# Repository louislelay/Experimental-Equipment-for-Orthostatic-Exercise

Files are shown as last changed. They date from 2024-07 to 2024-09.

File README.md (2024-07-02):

# Experimental Equipment for Orthostatic Exercise

This is the repository for the Experimental Equipment for Orthostatic Exercise project, developed by the Real World Robot Informatics Lab at the University of Tokyo. The goal is to create a robotic assistive system designed to aid individuals in standing up from a soft chair.

This project is part of the research conducted by Prof. Qi An. 

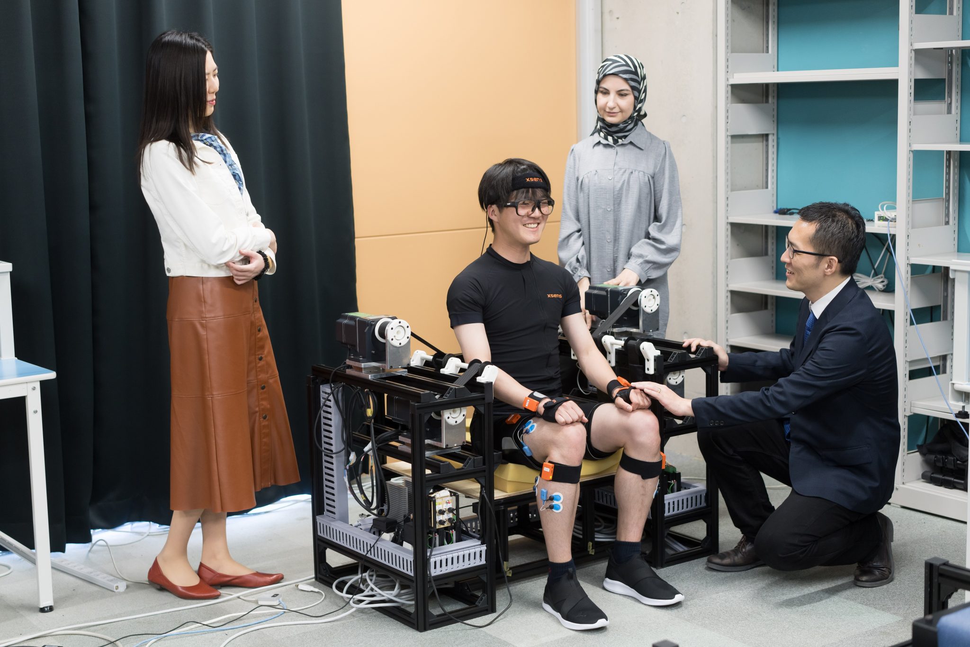
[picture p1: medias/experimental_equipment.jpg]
Experimental Equipment


[Real World Robot Informatics Lab's Website](https://www.robot.t.u-tokyo.ac.jp/yamalab/index.html)

[Qi An's Website](https://www.robot.t.u-tokyo.ac.jp/anlab/)

## Code

### Prerequisites

The project is implemented in MATLAB. Ensure you have MATLAB installed along with the "Data Acquisition Toolbox."

Additionally, two National Instruments libraries are required to interface with the National Instruments USB-6009 device. The executables, named "ni-daqmx_24.3_online.exe" and "ni-system-configuration_24.3_online.exe," are located at the root of the project.

All code files are located in the "src" folder.

### Calibration

Due to the initial force applied to the sensors, you must run the "calibration.m" program. Ensure the switch is set to remote mode.

This program will reverse the motors to loosen the strap and collect 1000 filtered values from all four sensors. It calculates the mean of these values, providing an offset applied in subsequent programs via a JSON file.

### Using the Chair (still in development)

To operate the chair, run the "main.m" program. This program instructs the motors to apply a 40N force to the strap using a PID loop. It monitors real-time values to detect when the user intends to stand. By increasing the force to 100N, the strap tightens, making it easier for the user to stand by converting the chair from soft to firm.

### Debugging

To read values in real-time and control the chair manually, run the "debug.m" program. By default, it won't display any values. You need to pass arguments to view specific data.

- `debug` - No display.
- `debug('-raw')` - Displays raw sensor values.
- `debug('-filt')` - Displays filtered sensor values.
- `debug('-calib')` - Displays calibrated, filtered values.
- `debug('-f')` - Displays resultant forces from each motor.

You can combine arguments to view multiple data sets simultaneously, such as `debug('-filt', '-calib')` to display both filtered and calibrated values.

These arguments are also applicable to the "main.m" program.

### Storing Data

To analyze the values and create a program that detects variations, we need to store data on the force evolution when someone is standing up from the chair. This is why we developed the program "get_values.m," which collects sensor information and stores it in "data_stored.mat." Each time, it will prompt for a name to be associated with the new data.

## CAD

The "cad" folder contains the SolidWorks CAD files for the project.

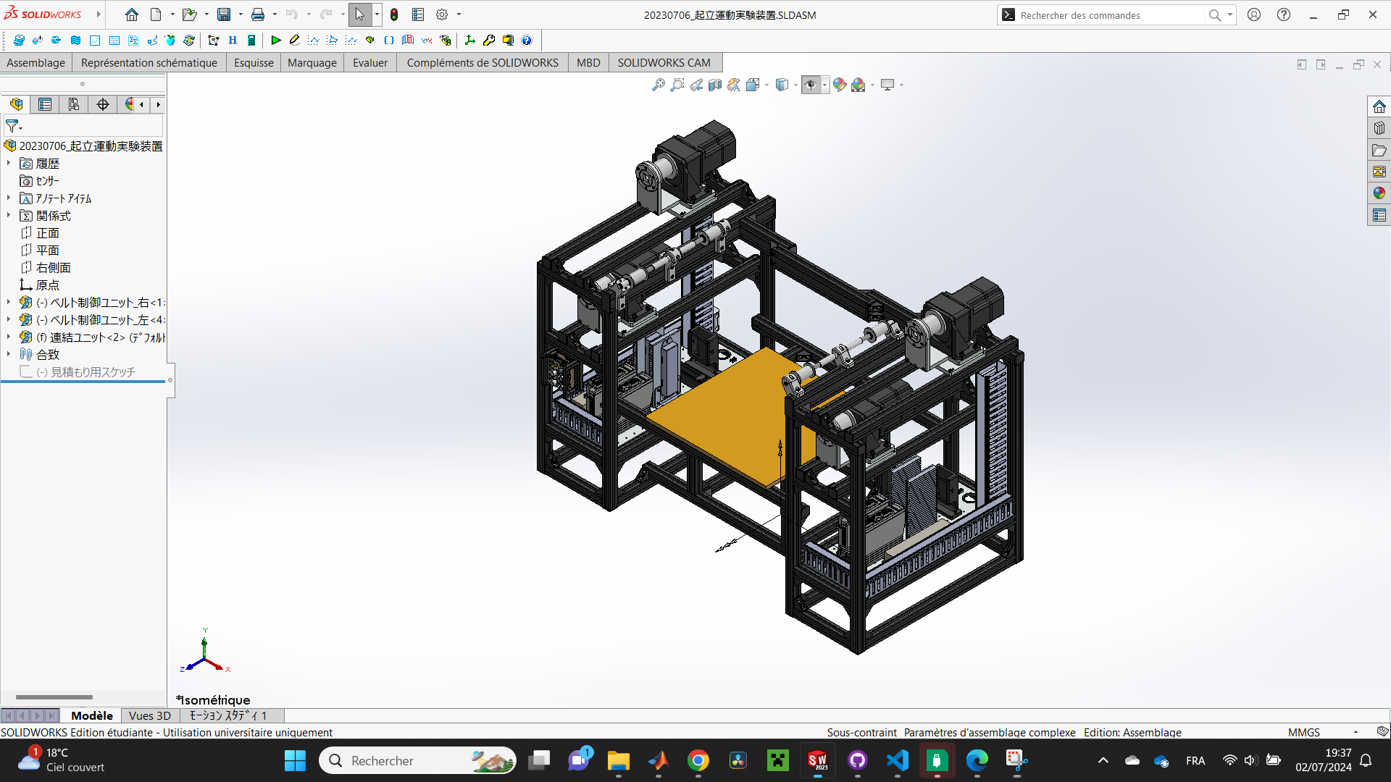
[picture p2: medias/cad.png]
CAD screenshot


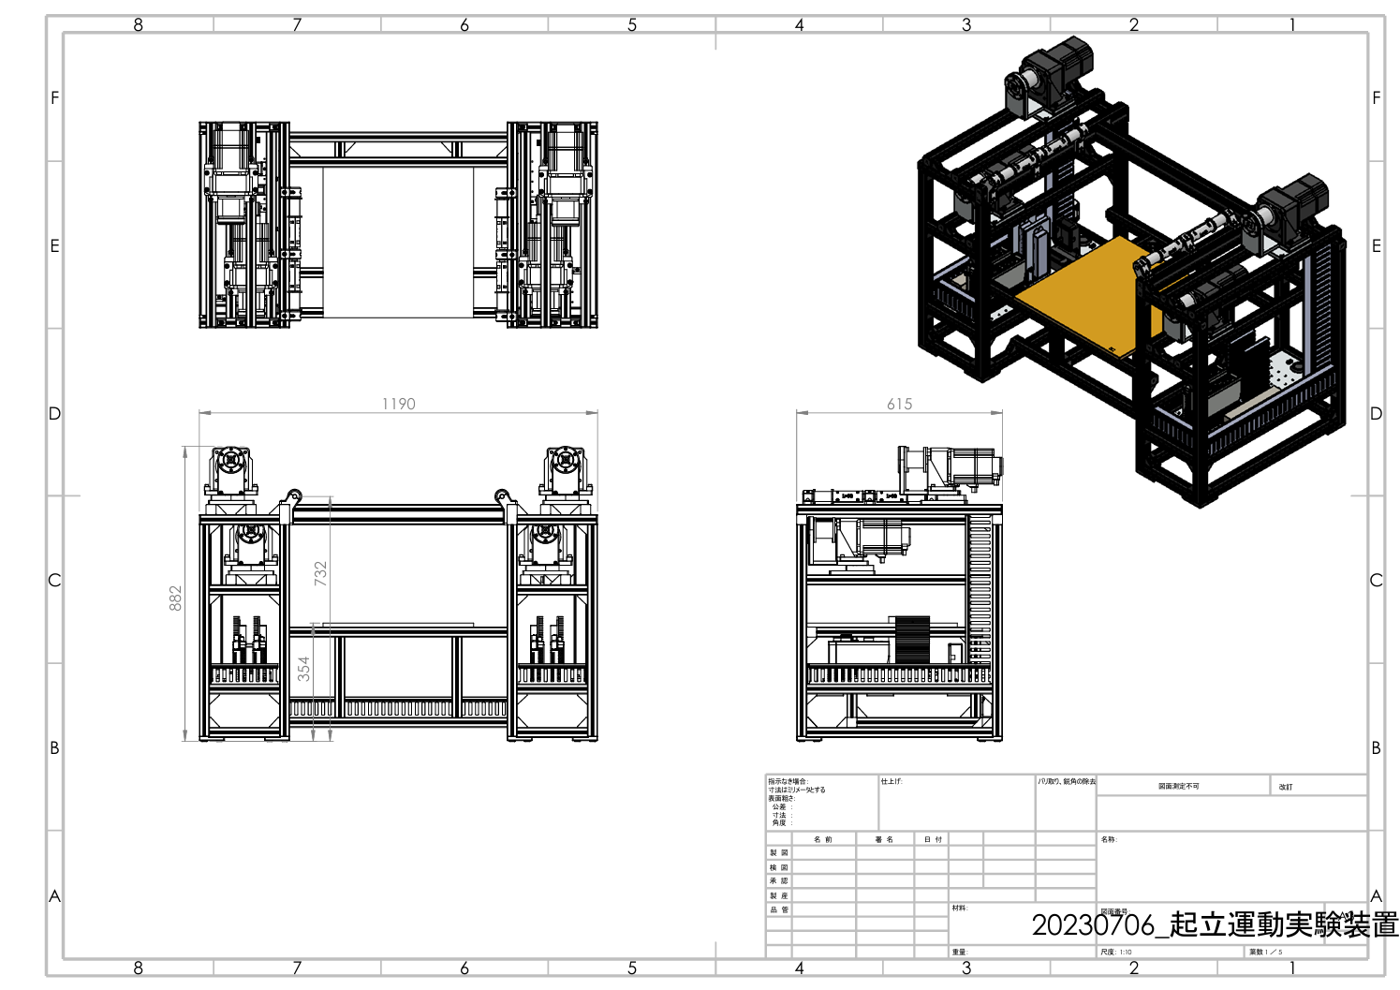
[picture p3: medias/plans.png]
Plans screenshot


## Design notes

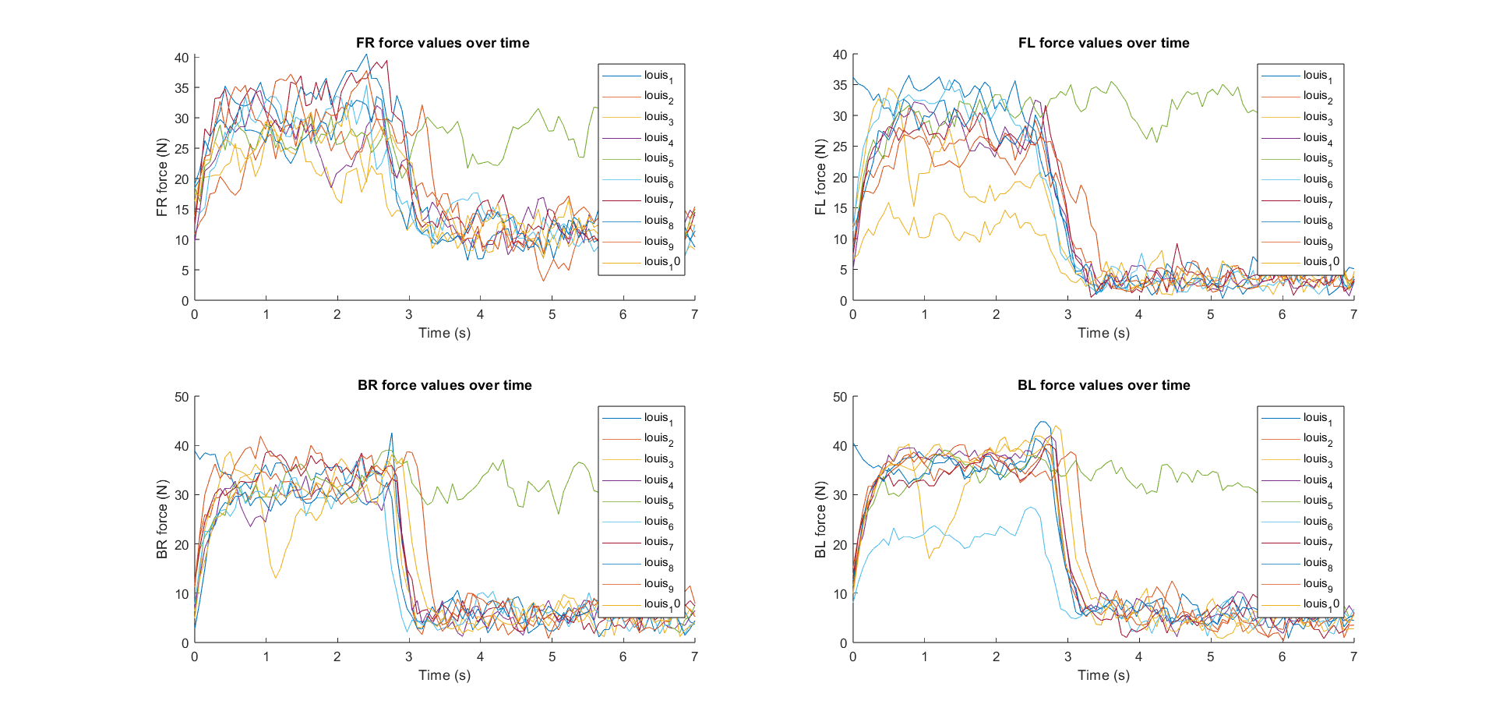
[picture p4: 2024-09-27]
src/treshold.png

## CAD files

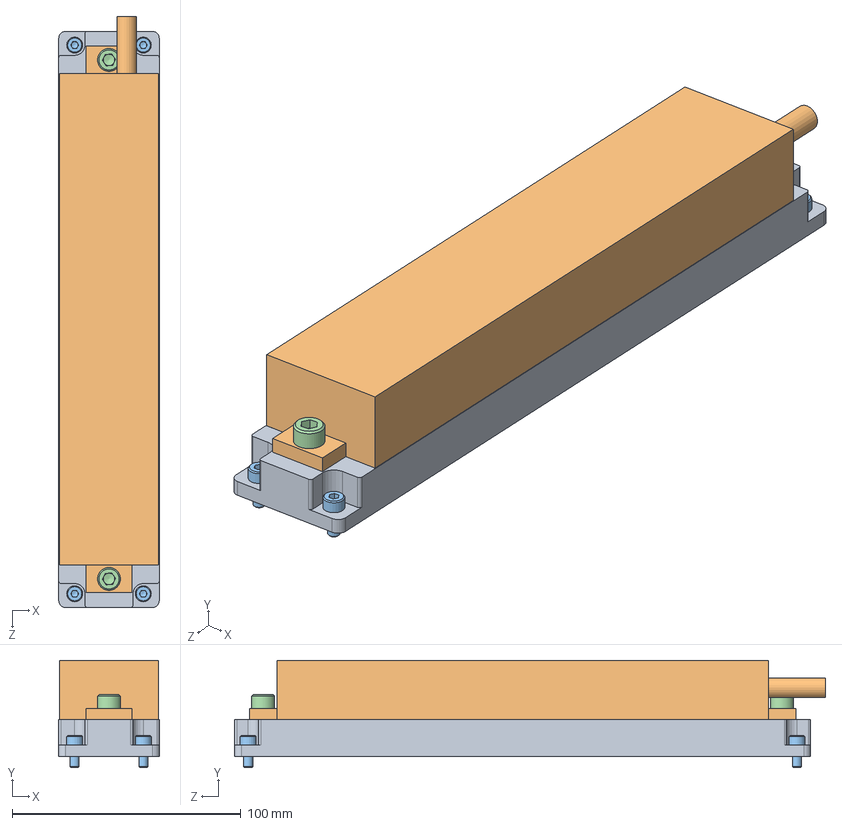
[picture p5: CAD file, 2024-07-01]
cad/コンセント.SLDASM
44.0 x 47.0 x 258.5 mm
TAP-K4-10用ベース
TAP-K4-10
CB4-10 x 4
CB6-12 x 2

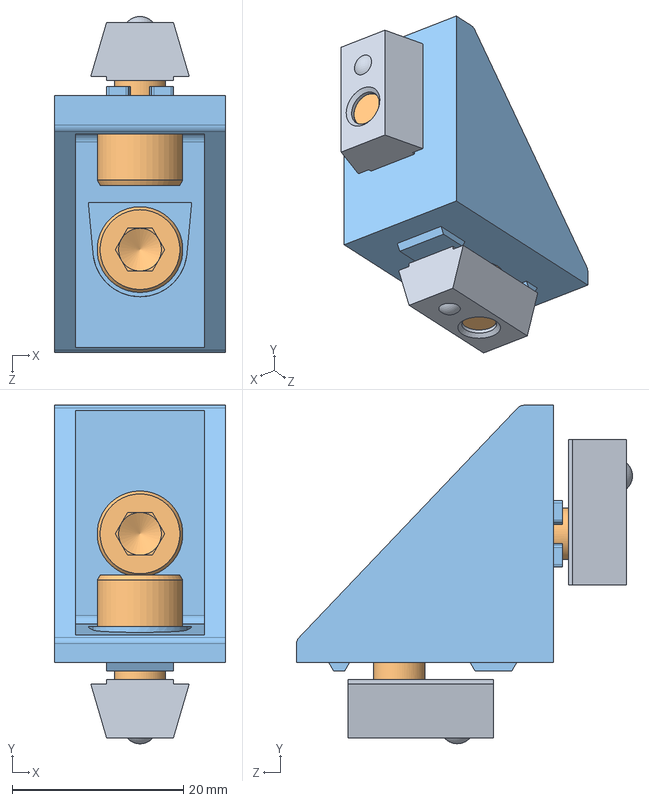
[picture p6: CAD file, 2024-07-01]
cad/HBLFSNB6-SEP.sldasm
20.0 x 39.5 x 39.2 mm
HNTP6-6_app x 2
HBLFSN6_CBM6-12 x 2
HBLFSNB6-SEP_b

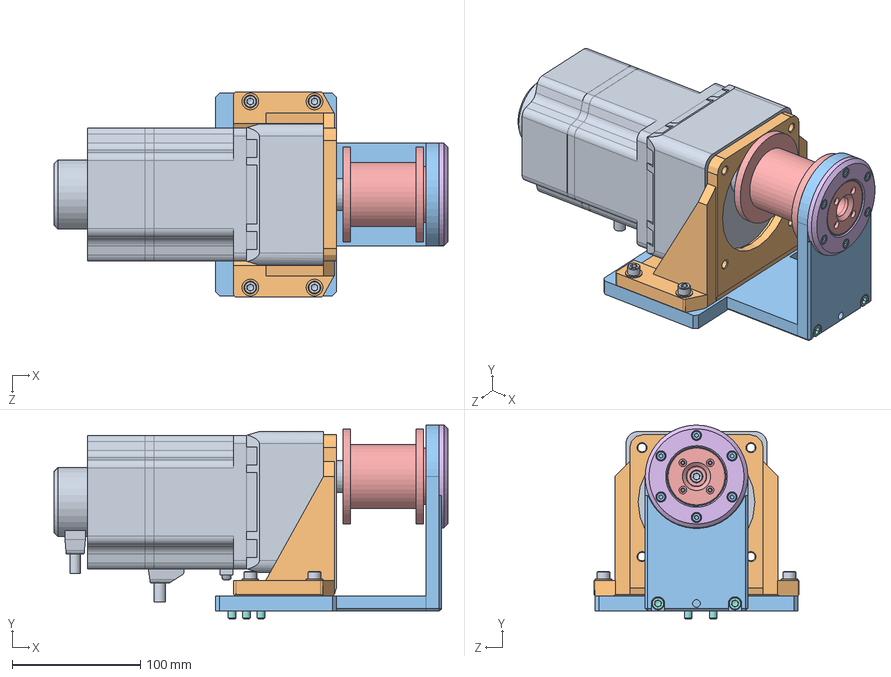
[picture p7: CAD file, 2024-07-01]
cad/モーターユニット.SLDASM
307.0 x 151.0 x 160.0 mm
BXM6200M-10
SOL6M8
モーターブラケット
6808ZZ
ベルト巻き取りドラム
ベアリングキャップ
MS6-60
CB6-12 x 5
CB6-20 x 5
WSJ-STN-M6 x 4
CB4-10 x 6

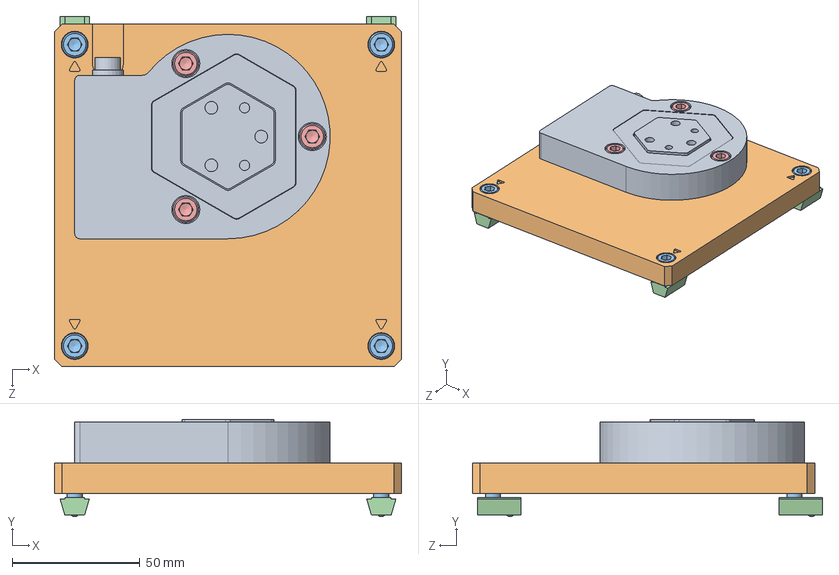
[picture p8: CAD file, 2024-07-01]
cad/モーターユニット架台.sldasm
136.0 x 38.1 x 137.0 mm
FFS080 v1
モーターユニット架台プレート
CB6-12 x 4
HNTP6-6_app x 4
CB6-20 x 3

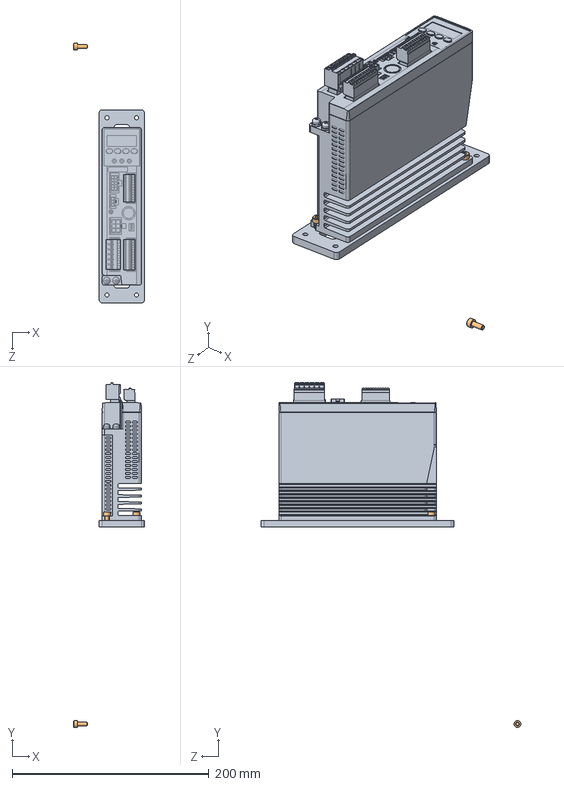
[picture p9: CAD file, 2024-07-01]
cad/モータードライバ.SLDASM
72.0 x 350.3 x 263.8 mm
BXSD200-A2
CB4-10 x 6

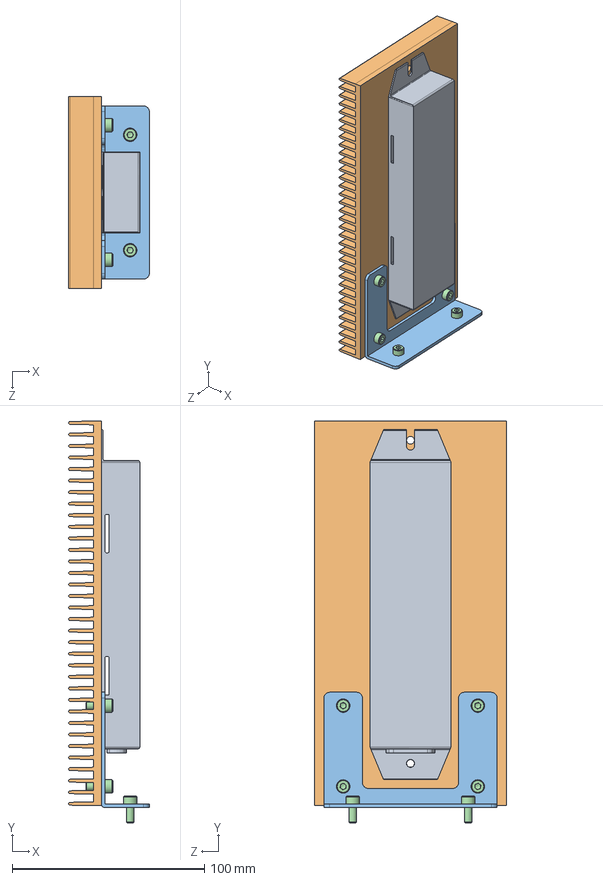
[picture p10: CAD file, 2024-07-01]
cad/抵抗器.SLDASM
42.0 x 209.0 x 100.0 mm
RGB100
17F200L100
抵抗器用ブラケット
CB4-10 x 6

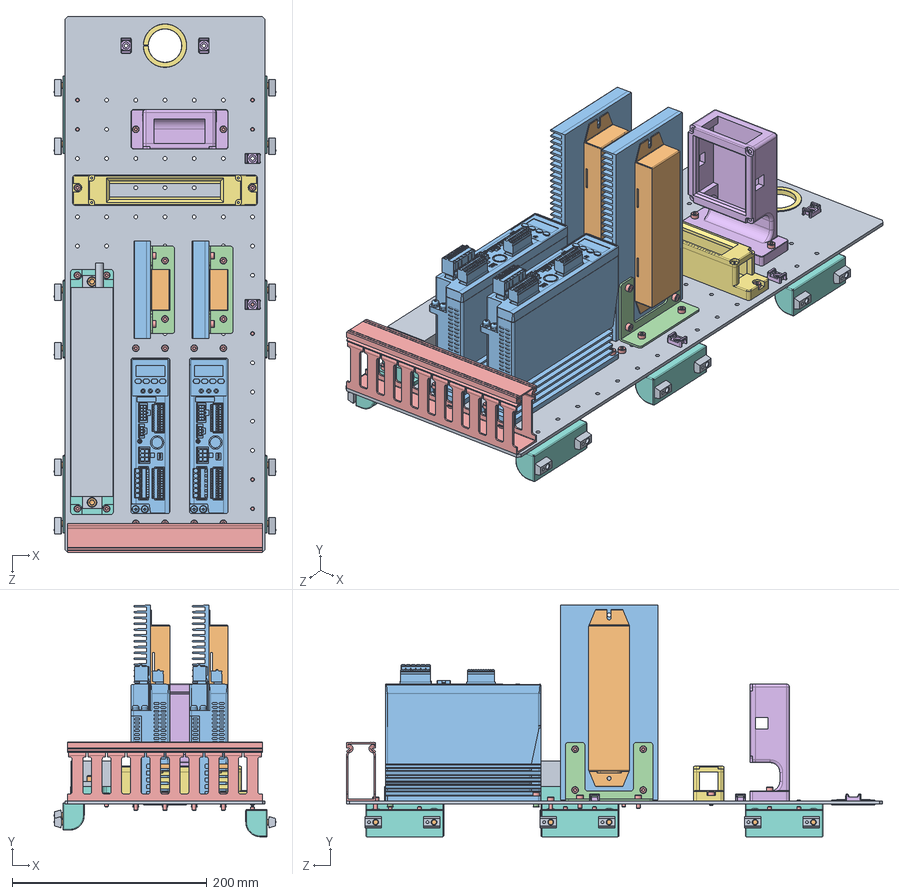
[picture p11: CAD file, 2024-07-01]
cad/中板ユニット_右用.sldasm
228.2 x 238.0 x 551.0 mm
中板
RGB100 x 2
17F200L100 x 2
抵抗器用ブラケット x 2
CB4-10 x 44
AIO160802AY-USB用ケース2
U2H-Z7SBK_用ケース
TAP-K4-10用ベース
TAP-K4-10
CB6-12 x 14
BXSD200-A2 x 2
HFB-4001 x 4
KD-36-20-T_200
TM2S6-C x 4
NAE-032
中板受け用ブラケット x 6
HNTP6-6_app x 12

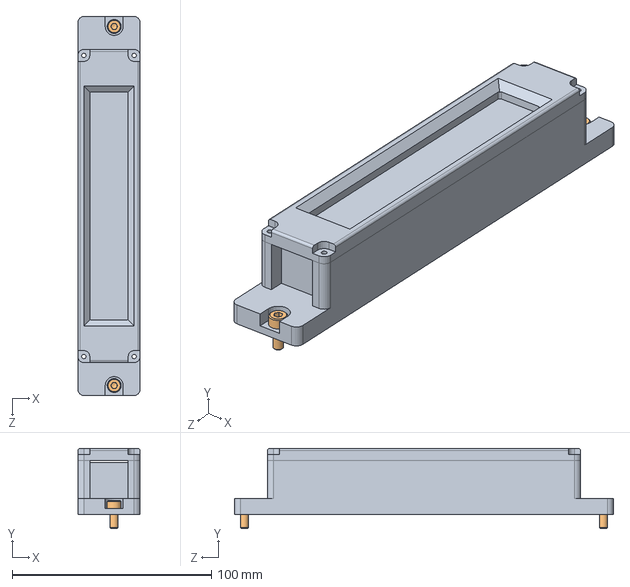
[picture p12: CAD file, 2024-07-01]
cad/USBハブ.SLDASM
31.2 x 40.2 x 190.0 mm
U2H-Z7SBK_用ケース
CB4-10 x 2

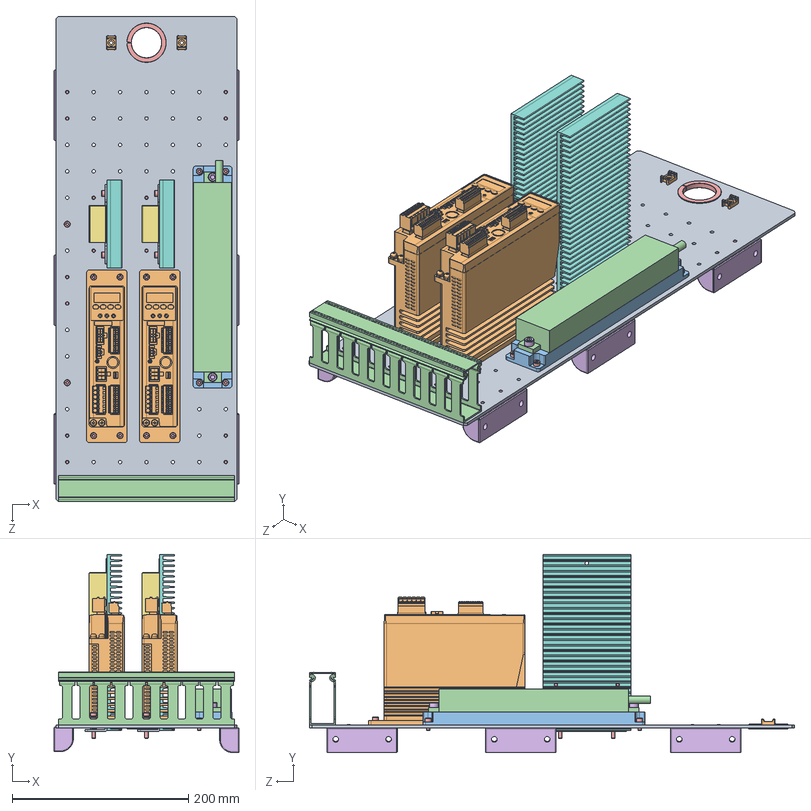
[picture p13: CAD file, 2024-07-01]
cad/中板ユニット_左用.sldasm
210.0 x 225.0 x 551.0 mm
中板
TM2S6-C x 2
TAP-K4-10用ベース
TAP-K4-10
CB4-10 x 42
CB6-12 x 2
RGB100 x 2
17F200L100 x 2
抵抗器用ブラケット x 2
BXSD200-A2 x 2
HFB-4001 x 4
KD-36-20-T_200
NAE-032
中板受け用ブラケット x 6

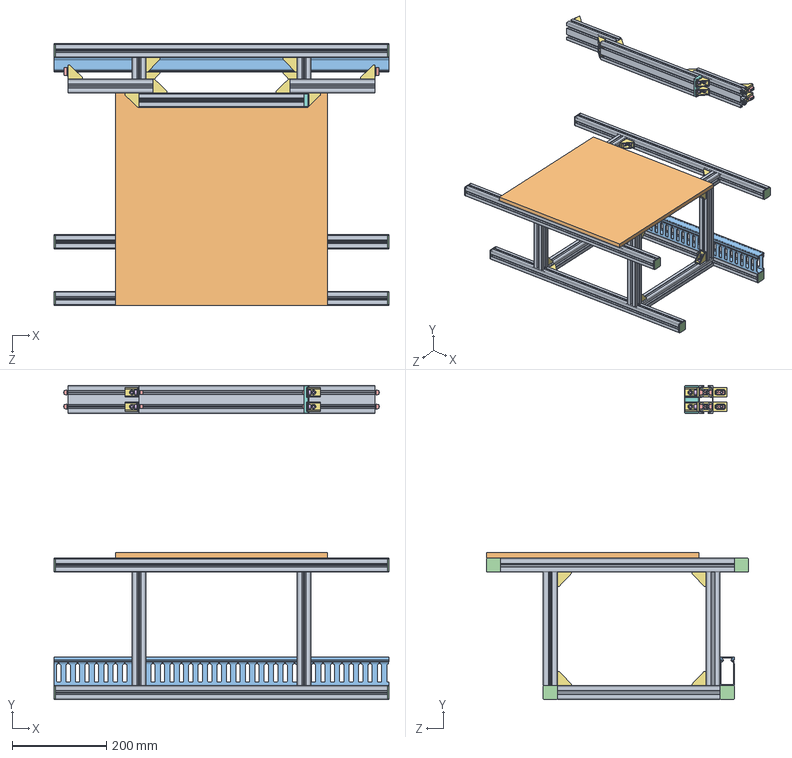
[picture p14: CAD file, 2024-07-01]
cad/連結ユニット.sldasm
710.0 x 666.0 x 555.0 mm
連結フレーム
パネコート合板
KD-36-20-T_710
HFC6-3030-B x 8
HNTP6-6_app x 60
HBLFSN6_CBM6-12 x 56
HBLFSNB6-SEP_b x 28
背もたれフレーム用カバー

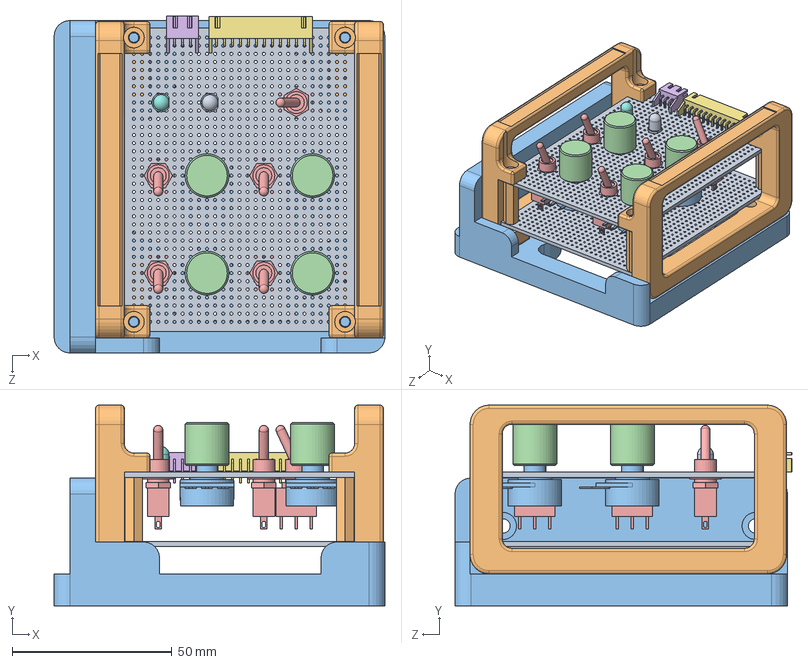
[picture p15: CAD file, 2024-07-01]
cad/コントローラ.SLDASM
103.5 x 62.8 x 105.4 mm
ユニバーサル基盤_9572b x 2
ASB-320E x 4
SW3dPS-Potentiometer x 4
サトーパーツ_K-29-6.1 x 4
User Library-7101SYZQE_switch-toggle x 5
S3B-XH-A
S12B-XH-A
ledverm5mmGa
ledverm5mmYa
カバー
コントローラ用マウンタ2

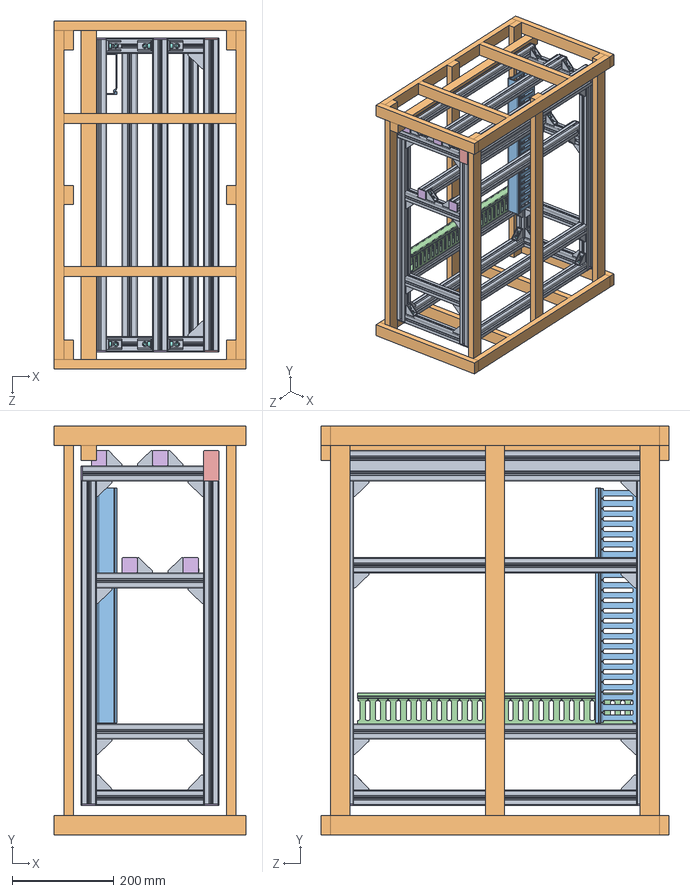
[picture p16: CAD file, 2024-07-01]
cad/筐体フレーム.sldasm
376.0 x 802.0 x 683.0 mm
筐体フレーム
配線ダクト用ブラケット x 2
KD-48-20-T
KD-36-20-T
HFC6-3060-B x 2
HFC6-3030-B x 14
HNTP6-6_app x 90
HBLFSN6_CBM6-12 x 90
HBLFSNB6-SEP_b x 45

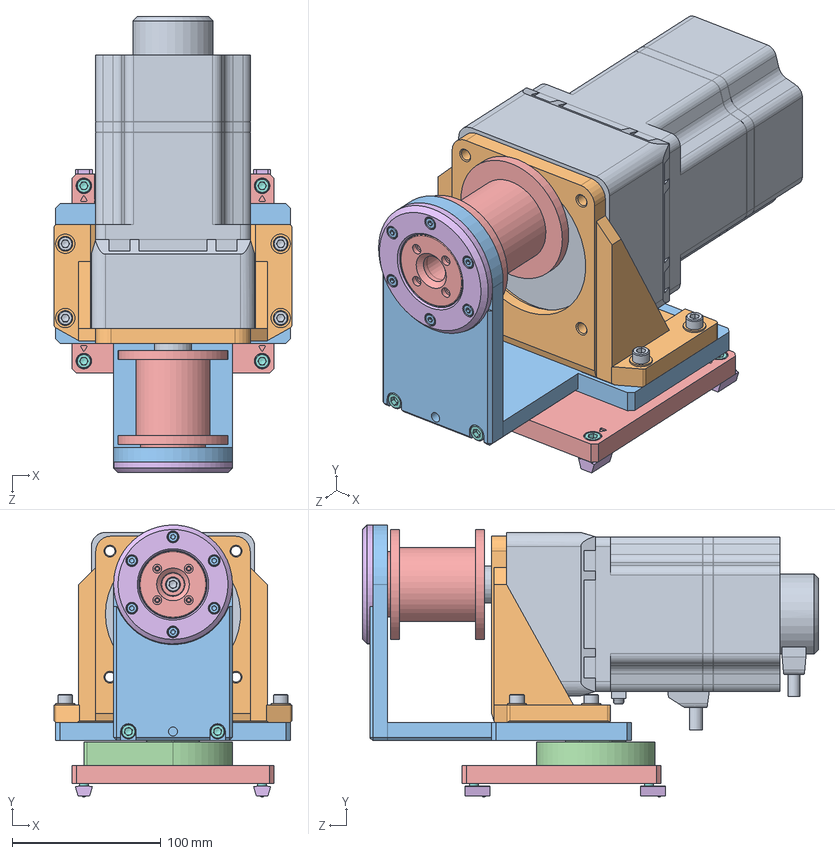
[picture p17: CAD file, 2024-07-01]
cad/ベルトドラムユニット.SLDASM
160.0 x 183.1 x 307.0 mm
BXM6200M-10
SOL6M8
モーターブラケット
6808ZZ
ベルト巻き取りドラム
ベアリングキャップ
MS6-60
CB6-12 x 9
CB6-20 x 8
WSJ-STN-M6 x 4
CB4-10 x 6
FFS080 v1
モーターユニット架台プレート
HNTP6-6_app x 4

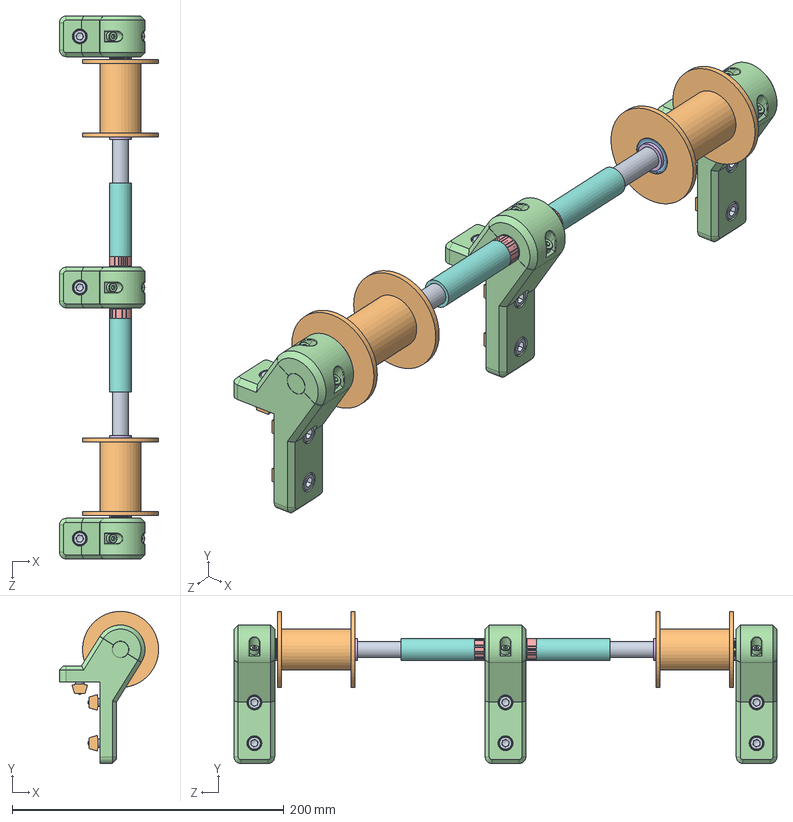
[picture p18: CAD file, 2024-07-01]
cad/ガイドローラーユニット.sldasm
73.0 x 112.0 x 399.6 mm
SFRW12-390-M6-N6_s
ガイドローラ_51x30 x 2
6801ZZ x 4
ガイドローラー用シャフトブラケット x 3
カラー_7 x 2
カラー_2 x 4
カラー_30 x 2
カラー_62 x 2
CB6-12 x 9
HNTP6-6_app x 9

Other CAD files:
cad/ガイドローラー.sldasm
cad/ベルト制御ユニット_左.sldasm
cad/ベルト制御ユニット_右.sldasm
cad/USB_IO.SLDASM
cad/17F200L100.SLDPRT
cad/6801ZZ.SLDPRT
cad/6808ZZ.SLDPRT
cad/AIO160802AY-USB用ケース2.SLDPRT
cad/ASB-320E.SLDPRT
cad/BXM6200M-10.SLDPRT
cad/BXSD200-A2.sldprt
cad/CB4-10.sldprt
cad/CB5-14.sldprt
cad/CB6-12.sldprt
cad/CB6-20.sldprt
cad/FFS080 v1.SLDPRT
cad/HBLFSN6_CBM6-12.sldprt
cad/HBLFSNB6-SEP_b.sldprt
cad/HFB-4001.SLDPRT
cad/HFC6-3030-B.sldprt
cad/HFC6-3060-B.sldprt
cad/HNTP6-5.sldprt
cad/HNTP6-6_app.sldprt
cad/KD-36-20-T.SLDPRT
cad/KD-36-20-T_200.SLDPRT
cad/KD-36-20-T_710.SLDPRT
cad/MS6-60.SLDPRT
cad/NAE-032.SLDPRT
cad/RGB100.SLDPRT
cad/S12B-XH-A.SLDPRT
cad/S3B-XH-A.SLDPRT
cad/SFRW12-390-M6-N6_s.sldprt
cad/SOL6M8.sldprt
cad/SW3dPS-Potentiometer.SLDPRT
cad/TAP-K4-10.SLDPRT
cad/TAP-K4-10用ベース.SLDPRT
cad/TM2S6-C.SLDPRT
cad/U2H-Z7SBK_用ケース.SLDPRT
cad/User Library-7101SYZQE_switch-toggle.SLDPRT
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

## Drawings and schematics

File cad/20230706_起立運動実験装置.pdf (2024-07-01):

E | E
F | F

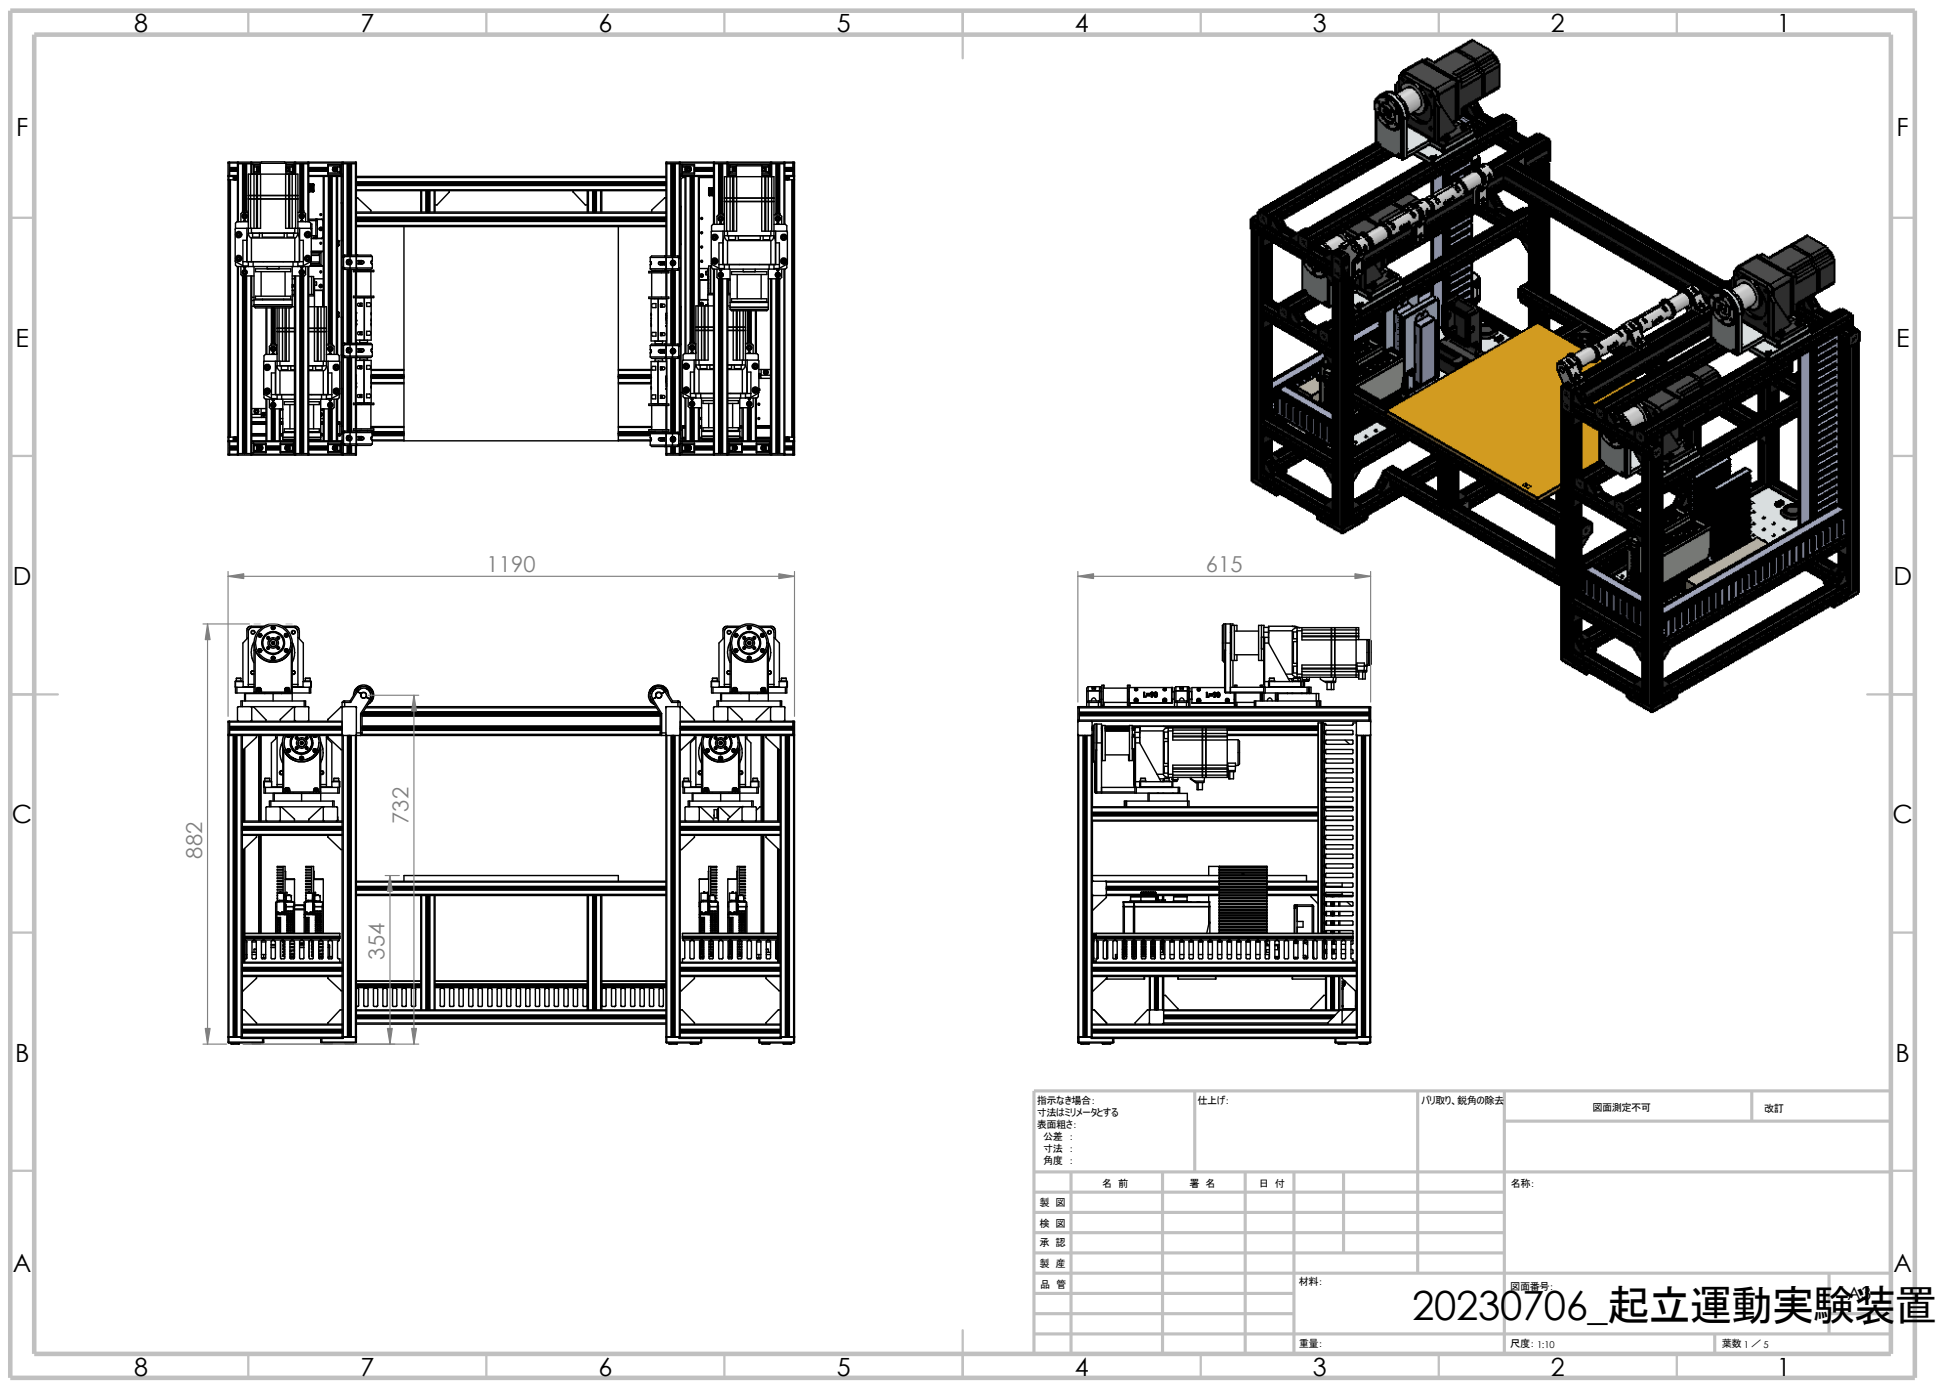
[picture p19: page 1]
20230706_起立運動実験装置; 図面測定不可; 仕上げ：; バリ取り、鋭角の除去; 指示なき場合： 寸法はミリメータとする 表面粗さ： 公差 ： 寸法 ：

検 図
承 認

製 産
品 管 | | | | 材料： | 図面番号： | A3

部品番号 部品番号 | 部品名 部品名 | 注記 注記 | 個数 個数
1 | ベルト制御ユニット_右 | 1
2 2 | ベルト制御ユニット_左 ベルト制御ユニット_左 | 1 1
3 | 連結ユニット | 1
1 | ベルト制御ユニット_右 | 1
3 | 連結ユニット | 1

検 図

承 認
A | A
B | | B
| 名 前 | 署 名 | 日 付 | 名称：
C | C
D | D
E | E
F | F
重量： | 尺度： 1:10 | 葉数 2 ／ 5
図面測定不可 | 改訂

バリ取り、鋭角の除去

製 産

角度 ：

指示なき場合： | 仕上げ：
寸法はミリメータとする
表面粗さ：
公差 ：
寸法 ：

製 図

2

3

1

E | E
F | F

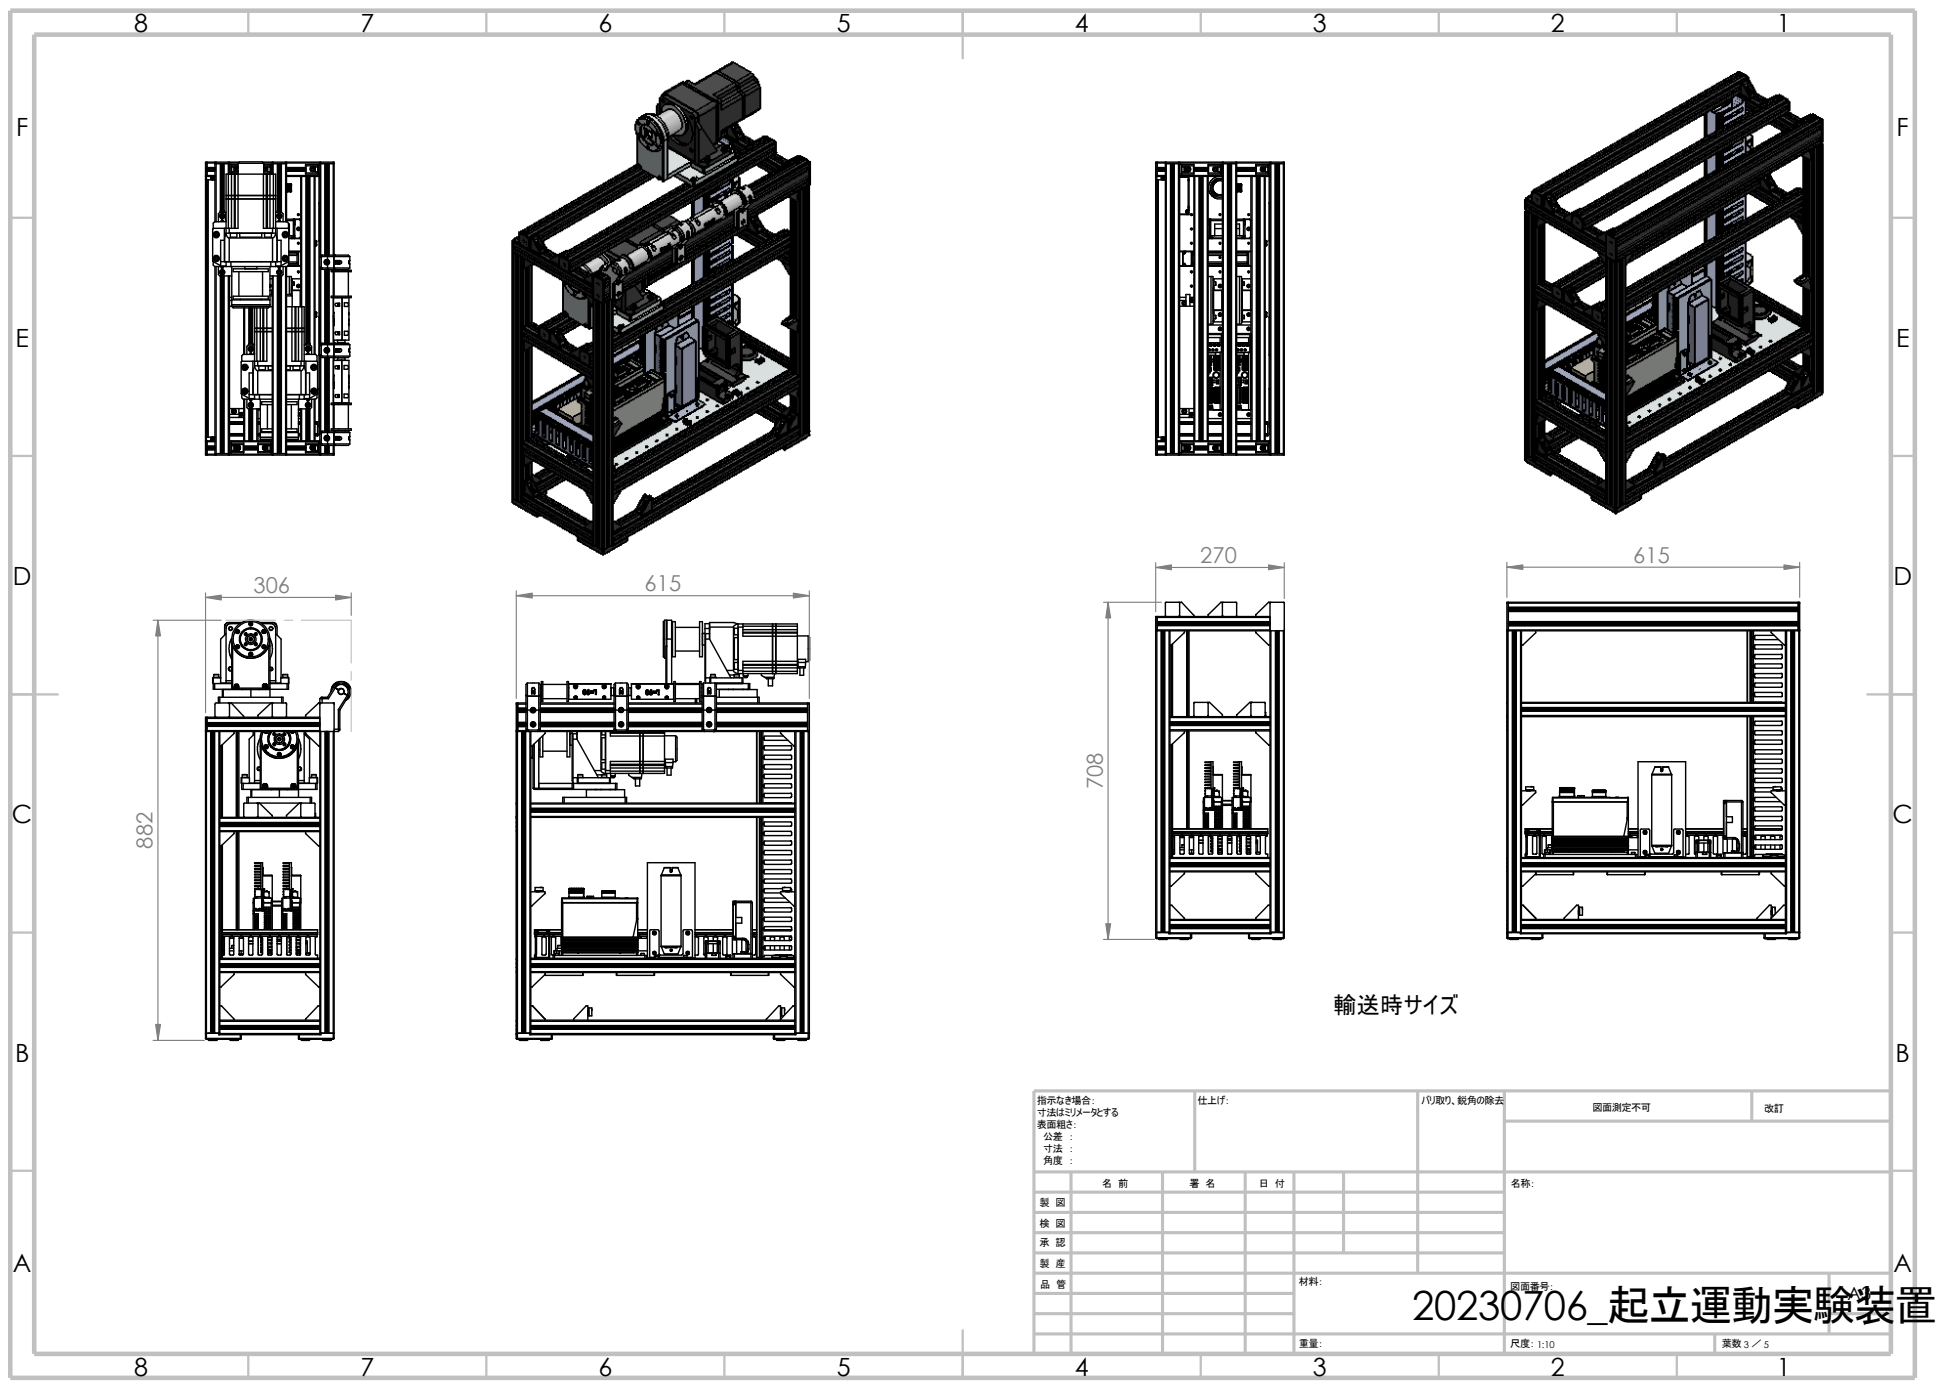
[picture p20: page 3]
図面測定不可; 指示なき場合：; 仕上げ：; バリ取り、鋭角の除去; 寸法はミリメータとする 表面粗さ： 公差 ： 寸法 ：; 輸送時サイズ

検 図
承 認

20230706_起立運動実験装置 尺度： 1:10 | 葉数 3 ／ 5

E | E
F | F

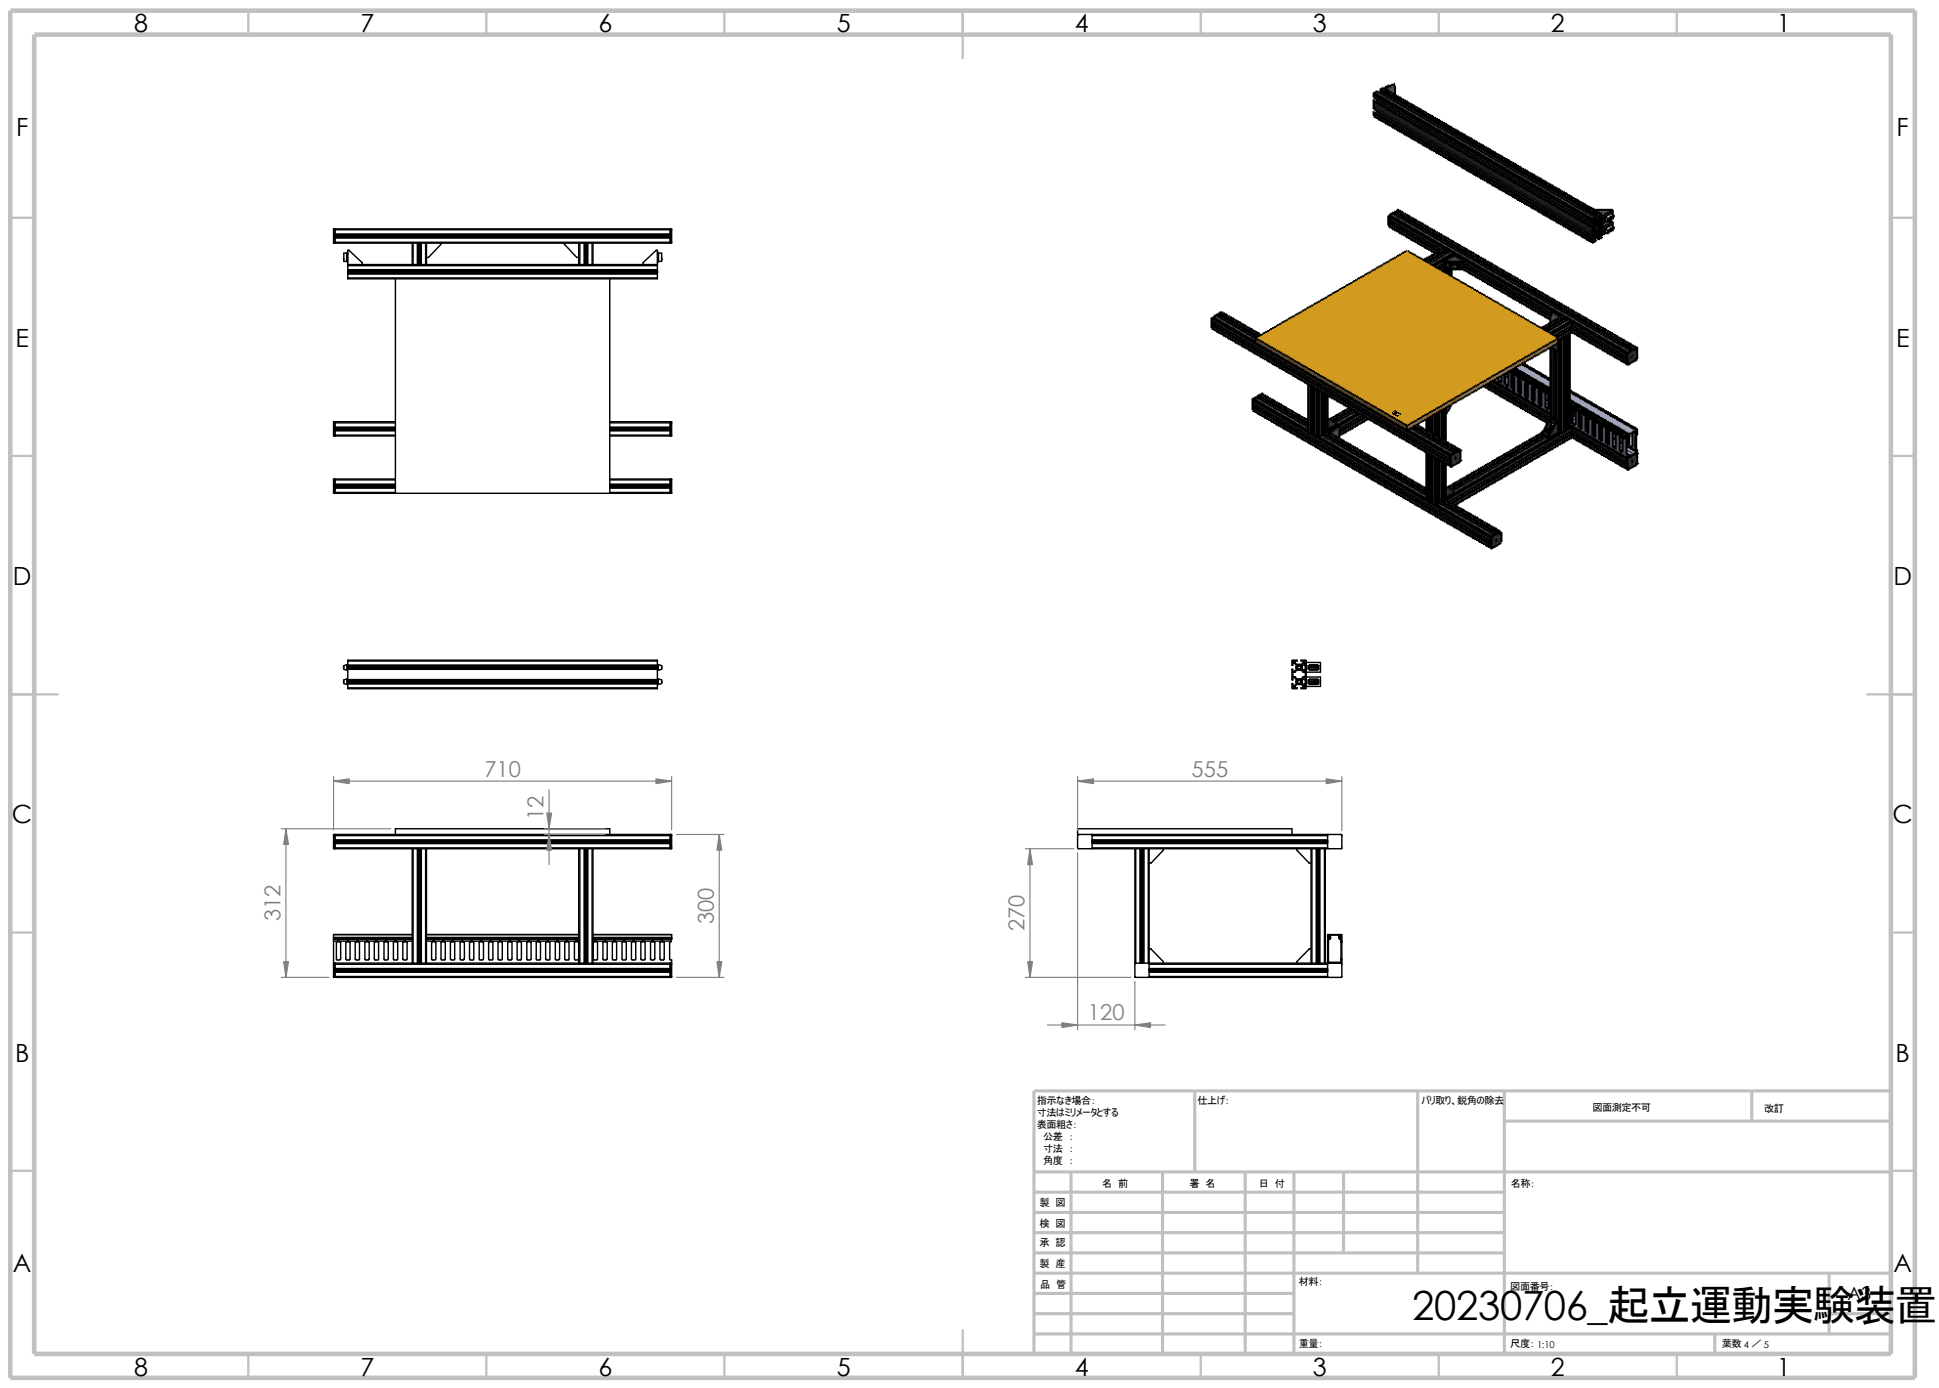
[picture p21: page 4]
図面測定不可; バリ取り、鋭角の除去; 指示なき場合：; 仕上げ：; 寸法はミリメータとする 表面粗さ： 公差 ： 寸法 ：

検 図
承 認

E | E
F | F

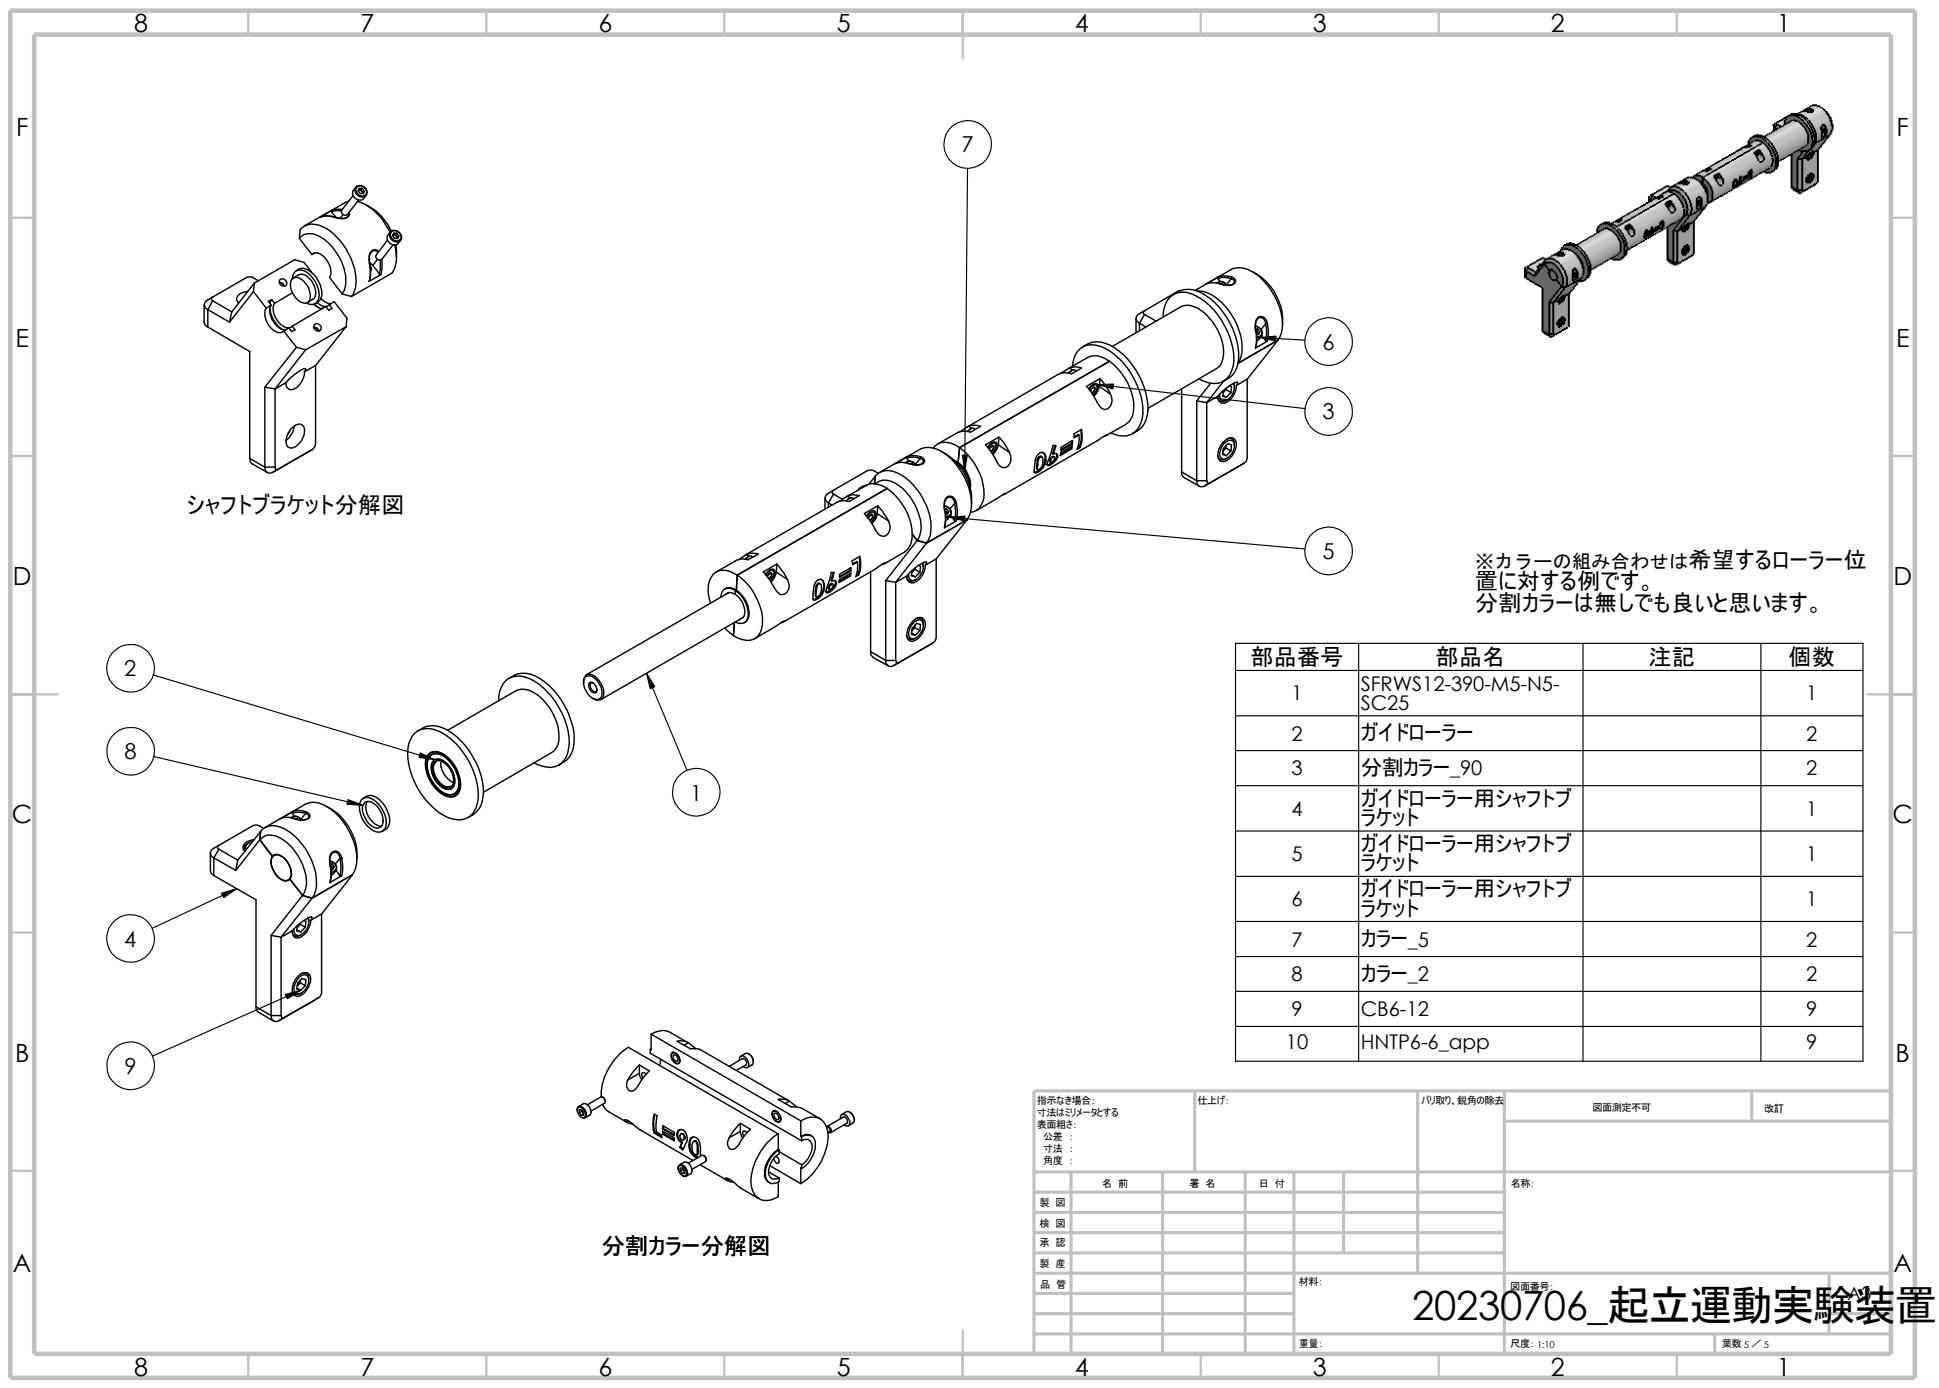
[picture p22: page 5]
※カラーの組み合わせは希望するローラー位 置に対する例です。 分割カラーは無しでも良いと思います。; 分割カラー分解図; 図面測定不可; 指示なき場合：; 仕上げ：; バリ取り、鋭角の除去; 寸法はミリメータとする 表面粗さ： 公差 ： 寸法 ：; シャフトブラケット分解図

部品番号 | 部品名 | 注記 | 個数
1 | SFRWS12-390-M5-N5-SC25 | | 1

2 | ガイドローラー | | 2
3 | 分割カラー_90 | | 2
4 | ガイドローラー用シャフトブ ラケット | | 1

5 | ガイドローラー用シャフトブ ラケット | | 1

6 | ガイドローラー用シャフトブ ラケット | | 1

7 | カラー_5 | | 2
8 | カラー_2 | | 2
9 | CB6-12 | | 9
10 | HNTP6-6_app | | 9

検 図
承 認

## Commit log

2024-07-01 creation of the repository, first commit
    [155_protection.SLDPRT, 155_protection.STL, 156_protection.SLDPRT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]
2024-07-01 calibration.m adding the calibration values to the json file
2024-07-01 using the json file to get the calibration value
2024-07-01 modifying the filters and trying new ones
2024-07-01 adapting debug to the changes of the new way to use filters
2024-07-02 work on the hand protection from the strap
    [protection hand.SLDPRT, protection hand.STL, protection_hand.SLDPRT]
2024-07-02 modifying a few things
    [protection hand.SLDPRT, vis.SLDPRT]
2024-07-02 adding screenshots of cad and plans
2024-07-04 cleaning up
    [155_protection.STL, 156_protection.STL, Pièce3.SLDPRT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]
2024-07-17 plot the other sensors
2024-07-17 changed a few things to modulate the time of action for the pid
2024-08-02 updated time for pid control to make it shorter
2024-08-09 changed the pid for 30n to be implemented in the loop
2024-08-09 augmented the clamping for the volltage
2024-08-09 augmenting the clamping of the voltage
2024-08-09 created a second pid program which also record the datz
2024-08-09 changing time for pid to be activate
